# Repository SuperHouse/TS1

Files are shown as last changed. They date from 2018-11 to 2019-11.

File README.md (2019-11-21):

Touch Switch 1
==============
Copyright 2018-2019 SuperHouse Automation Pty Ltd  www.superhouse.tv  

A simple single-channel touch switch controller with a switchmode
power supply and a linear regulator, to allow operation or input
voltages up to 28V such as a wheelchair battery.

Deliberately de-sensitised to require actual contact with the
touch pad, to prevent false triggering when a finger is held
near the pad without touching it.

Open-drain output that switches to GND via an N-MOSFET.

Features:

 * at42qt1010 touch sensor IC
 * 7-28Vdc supply voltage
 * Open-drain output
 * Power LED
 * Activity LED

You can view more online at:

  http://www.superhouse.tv/ts1

INSTALLATION
------------
The design is saved as an EAGLE project. EAGLE PCB design software is
available from www.cadsoftusa.com free for non-commercial use. To use
this project download it and place the directory containing these files
into the "eagle" directory on your computer. Then open EAGLE and
navigate to the project.

DISTRIBUTION
------------
The specific terms of distribution of this project are governed by the
license referenced below.

LICENSE
-------
Licensed under the TAPR Open Hardware License (www.tapr.org/OHL).
The "license" folder within this repository also contains a copy of
this license in plain text format.

CREDITS
-------
Designed by Jonathan Oxer (jon@oxer.com.au)

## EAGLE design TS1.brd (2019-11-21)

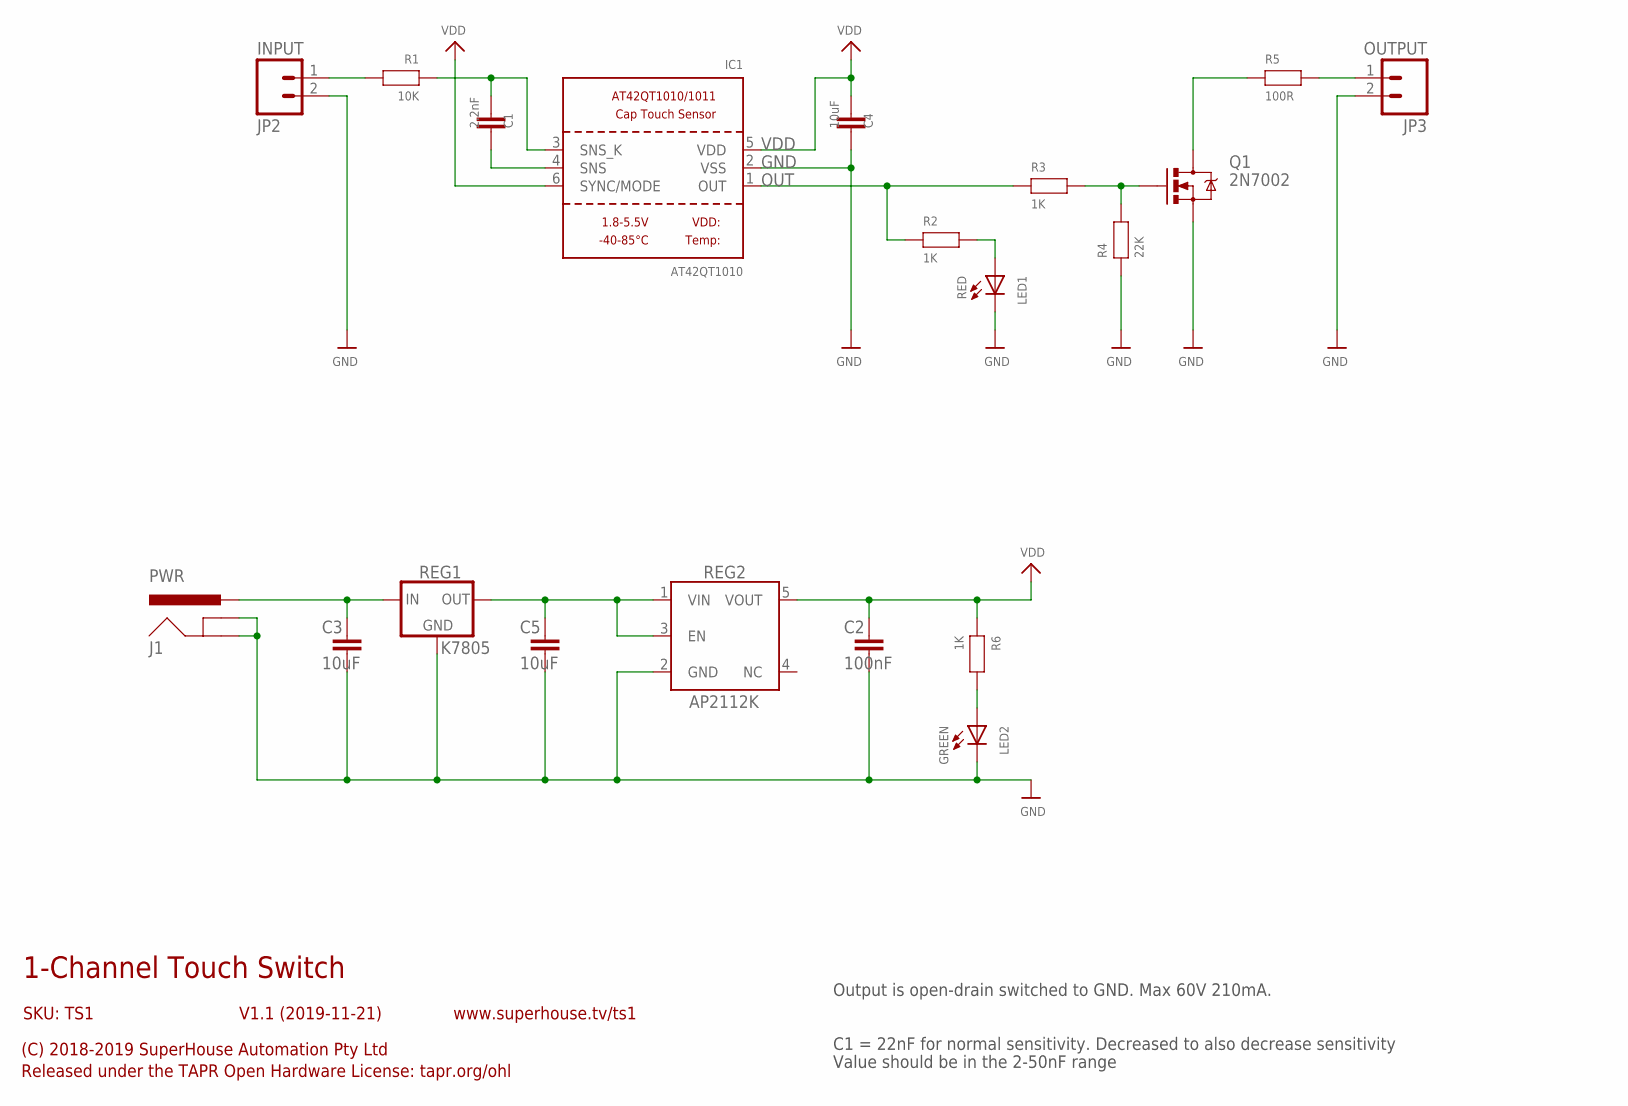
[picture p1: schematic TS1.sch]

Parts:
C1: 2.2nF; C0603
C2: 100nF; C0603
C3, C4, C5: 10uF; C0603
IC1: AT42QT1010; SOT23-6
J1: PWR; POWER_JACK_SLOTS
JP2: INPUT; 1X02-S
JP3: OUTPUT; 1X02-S
LED1: RED; LED-0603
LED2: GREEN; LED-0603
Q1: 2N7002; SOT23-3
R1: 10K; R0603
R2, R3, R6: 1K; R0603
R4: 22K; R0603
R5: 100R; R0603
REG1: K7805; K78XX-500R3
REG2: AP2112KSOT25; SOT23-5

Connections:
CAPPAD: JP2.1, R1.2
GND: C2.2, C3.2, C4.2, C5.2, IC1.2 (VSS), J1.GND, J1.GNDBREAK, JP2.2, JP3.2, LED1.C, LED2.C, Q1.2 (S), R4.1, REG1.2 (GND), REG2.2 (GND)
unnamed: JP3.1, R5.2
unnamed: Q1.3 (D), R5.1
unnamed: C1.2, IC1.4 (SNS)
unnamed: C1.1, IC1.3 (SNS_K), R1.1
unnamed: Q1.1 (G), R3.2, R4.2
unnamed: LED1.A, R2.2
unnamed: C3.1, J1.PWR, REG1.1 (IN)
unnamed: C5.1, REG1.3 (OUT), REG2.1 (VIN), REG2.3 (EN)
unnamed: LED2.A, R6.2
OUT: IC1.1 (OUT), R2.1, R3.1
VDD: C2.1, C4.1, IC1.5 (VDD), IC1.6 (SYNC/MODE), R6.1, REG2.5 (VOUT)

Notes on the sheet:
1-Channel Touch Switch
V1.1 (2019-11-21)
(C) 2018-2019 SuperHouse Automation Pty Ltd
Released under the TAPR Open Hardware License: tapr.org/ohl
www.superhouse.tv/ts1
SKU: TS1
C1 = 22nF for normal sensitivity. Decreased to also decrease sensitivity
Value should be in the 2-50nF range
Output is open-drain switched to GND. Max 60V 210mA.

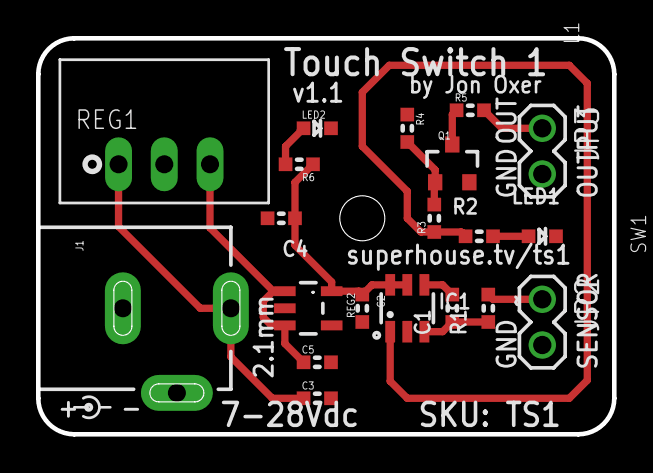
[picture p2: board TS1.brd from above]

Board: 2 copper layers, 32.0 x 22.0 mm, 20 parts (0 on the bottom side), 13 nets.

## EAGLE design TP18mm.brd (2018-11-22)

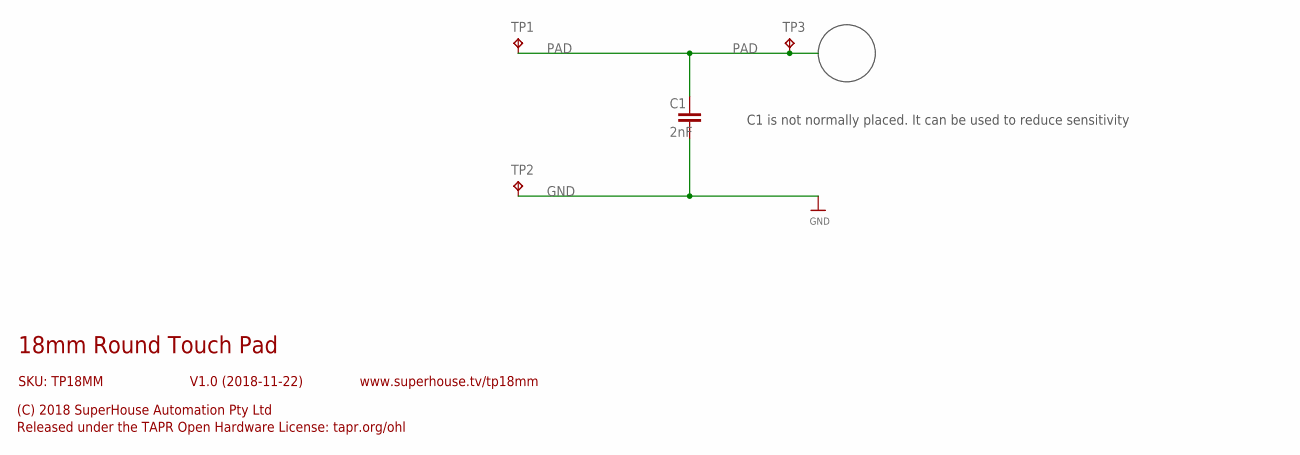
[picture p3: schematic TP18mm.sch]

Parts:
C1: 2nF; 0603
TP1, TP2, TP3: TPB2,54; B2,54

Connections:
GND: C1.2, TP2.TP
PAD: C1.1, TP1.TP, TP3.TP

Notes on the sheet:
18mm Round Touch Pad
V1.0 (2018-11-22)
(C) 2018 SuperHouse Automation Pty Ltd
Released under the TAPR Open Hardware License: tapr.org/ohl
www.superhouse.tv/tp18mm
SKU: TP18MM
C1 is not normally placed. It can be used to reduce sensitivity

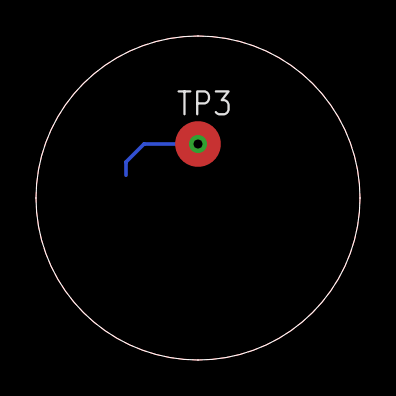
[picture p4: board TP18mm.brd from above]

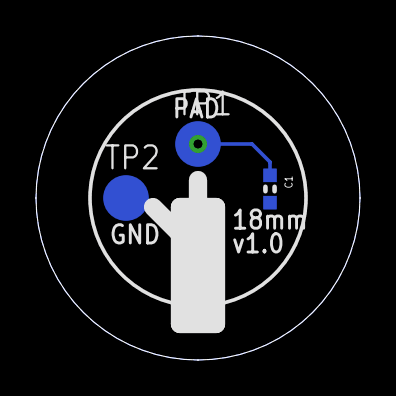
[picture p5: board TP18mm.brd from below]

Board: 2 copper layers, 18.0 x 18.0 mm, 4 parts (3 on the bottom side), 2 nets.

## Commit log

2018-11-21 Initial project import for v1.0 release
    [TS1.brd, TS1.sch]
2018-11-21 Fixed SKU and URL in schematic
    [TS1.sch]
2018-11-22 Added mounting hole
    [TS1.brd]
2018-11-22 Added 18mm touch pad
    [TP18mm.brd, TP18mm.sch]
2019-04-24 Updated footprints
    [TS1.brd, TS1.sch]
2019-11-21 Pulled back GND plane around input to sensor IC to reduce capacitive loading
    [TS1.brd, TS1.sch]
2019-11-21 Moved bypass cap closer to touch sensor IC
    [TS1.brd, TS1.sch]

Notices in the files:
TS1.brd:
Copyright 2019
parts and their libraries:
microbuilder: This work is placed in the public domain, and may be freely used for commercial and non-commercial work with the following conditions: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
